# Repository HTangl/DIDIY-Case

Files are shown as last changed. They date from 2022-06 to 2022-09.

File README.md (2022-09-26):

# DIDIY Case

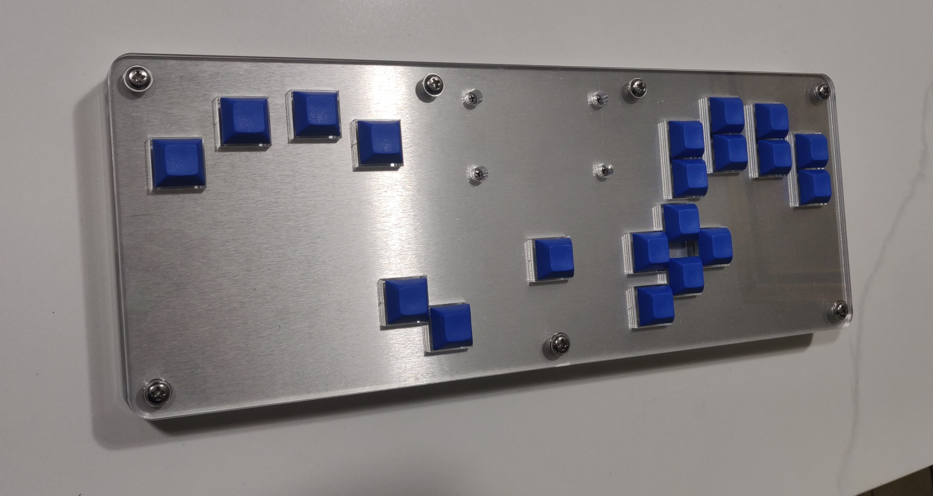
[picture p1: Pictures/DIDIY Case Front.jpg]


The DIDIY case is a case design specifically made for the [DIDIY board](https://github.com/HTangl/DIDIY). It uses the **[HTangl layout](https://www.htangl.com/layout)**

For a video guide on how to assemble the layered version of the case please visit the [HTangl YouTube channel](https://www.youtube.com/channel/UCIHJYzL-LAS2CVR-Q0J305w).  
Although this guide only shows the layered case the assembly is essentially the same for the 3D printable version, there are just less layers since the main part of the case is one big piece.
 
There are 2 versions of the case in this repository

## Layered Version

You can use the DXF files to order all the panels needed from a laser cutting website like [SendCutSend](https://sendcutsend.com/). There are other websites you can get the panels from, SCS is just the site I use. There is a guide on how to order the panels from SCS below.

If you would like to have 2 extra menu buttons for Select/Home make sure to use the DXF files in the "Select and Home buttons" folder. These replace the standard switch plate and top panel DXF files.

## 3D Printable Version

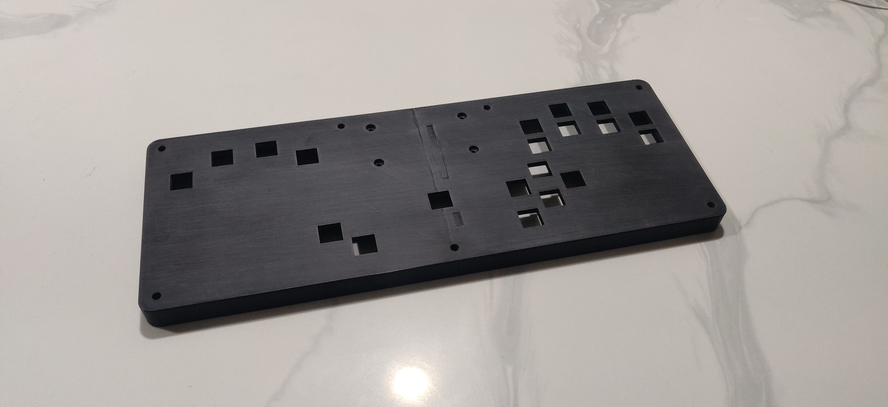
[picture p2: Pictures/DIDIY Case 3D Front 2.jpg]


You can use the STL files to print a case yourself, this version of the case still requires the hardware listed below minus the 8 M3 washers.

The main body of the case is printed in 2 halves which then slot together and are glued in place, while you can use super glue I recommend using a strong 2 part epoxy such as JB weld. The surface area is somewhat limited so the stronger the glue the better.

There are a few different ways to print a case, below are some suggestions.

**Fully Printed Option** - Print the main case + bottom and top panel, make sure to use the files in the "Select and Home buttons" folder if you want those buttons. You can exclude the top panel if you want to save filament/time, if you do this you will need to use 18mm case screws instead of the default 25mm ones.

**Print + Laser Cut Option** - Print the main case then use the DXF files to order 2 3mm top panels and 1 3mm bottom panel from SendCutSend, I recommend clear acrylic but you can use any material you want. This method has the advantage of allowing you to easily add artwork to the case. It also adds a little bit of rigidity because the top and bottom panels will be one big piece instead of split.

## Adding Artwork

If you want to add artwork to your case you can use the art template PDF's in this repository to design your own artwork and then either print it at home or at a print shop. I have a [guide on youtube](https://www.youtube.com/watch?v=gcbOZa_CNWk&t) that goes over how to prepare the file for printing, it was made for the HTangl but all the principals still apply.

## Hardware

For hardware you will need the following:  
7 - Case Screws - M5 x 0.80mm, 25mm Long  
7 - Case Nuts - M5 x 0.8 mm Weld Nuts  
4 - DIDIY Mounting Screws - M3 x 0.5mm, 8mm Long  
4 - DIDIY Mounting Nuts - M3 x 0.5 mm  
8 - Washers - M3 3.2 mm ID, 8 mm OD  

You can buy this hardware from me in a pack on my [Etsy shop](https://www.etsy.com/shop/HTangl) but if you'd prefer to source everything yourself below are links to the needed hardware on both McMaster-Carr and Amazon. McMaster will be higher quality but more expensive.  

McMaster-Carr  
https://www.mcmaster.com/92467A438/ - Case Screws  
https://www.mcmaster.com/90594A320/ - Case Nuts  
https://www.mcmaster.com/92000A118/ - DIDIY Mounting Screws  
https://www.mcmaster.com/91828A211/ - DIDIY Mounting Nuts  
https://www.mcmaster.com/95610A330/ - Washers  

Amazon  
https://amazon.com/dp/B08QHP1JK1 - Case Screws  
https://amazon.com/dp/B07H57TRN4 - Case Nuts  
https://amazon.com/dp/B01BBOZGKC - DIDIY Mounting Screws  
https://amazon.com/dp/B01IWUSDYY - DIDIY Mounting Nuts  
https://amazon.com/dp/B07MX9BMXM - Washers  

## SCS Ordering Guide

Here's a list of the material/thickness/quantity needed for each panel:  
Bottom Panel - Clear Acrylic 3mm - 1  
Middle Bottom Panel - Clear Acrylic 3mm - 2  
Middle Top Panel - Clear Acrylic 3mm - 3  
Switch Plate - 5052 Aluminum 1.6mm - 1  
Top Panel - Clear Acrylic 3mm - 2  

**Step 1**  
Download this repository by clicking on the green "Code" button at the top right of the page and then click "Download ZIP". Unzip the folder once it finishes downloading.  

**Step 2**  
Go to [SendCutSend](https://sendcutsend.com/) and click on "Get and instant quote"  
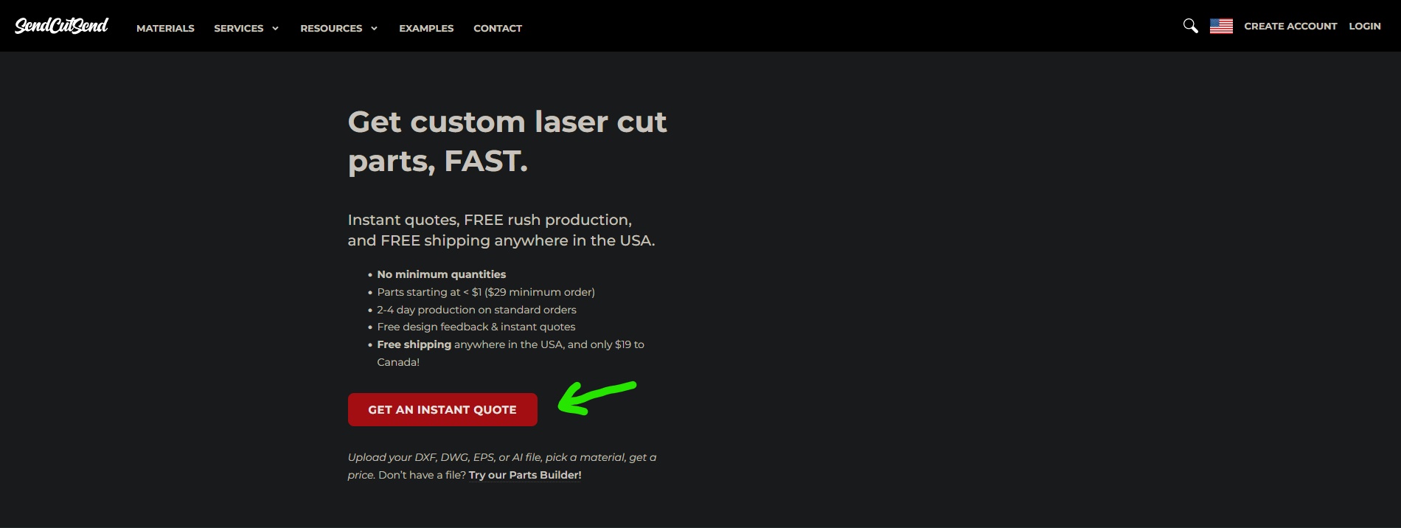
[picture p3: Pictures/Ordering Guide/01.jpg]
  

**Step 3**  
Open the DXF folder you downloaded in step 1 and drag one of the files onto the page to begin the ordering process, I started with the bottom panel.  
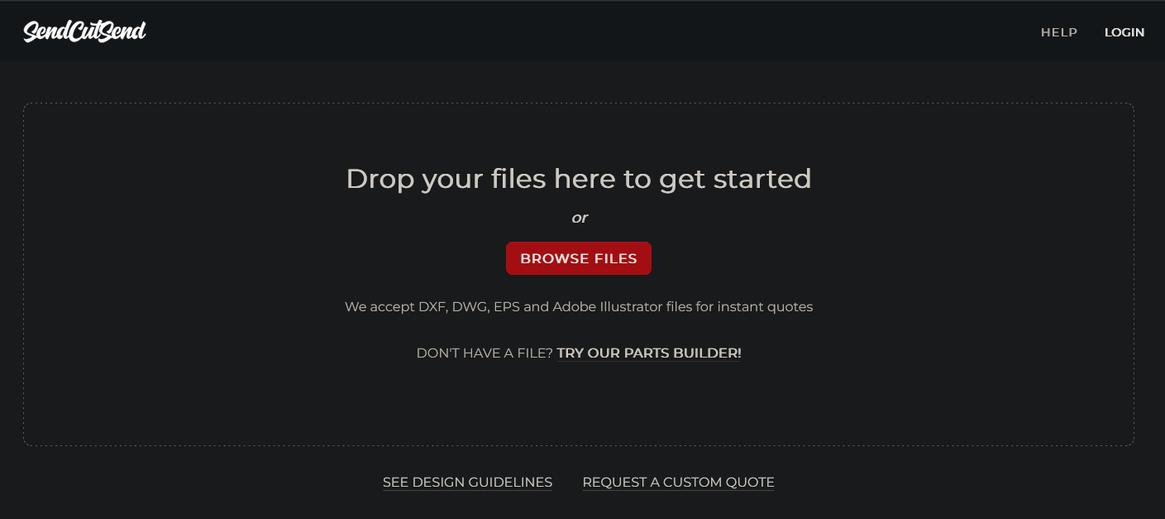
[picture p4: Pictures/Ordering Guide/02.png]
  

**Step 4**  
Click on the "Add to cart" button next to the file you just uploaded.  
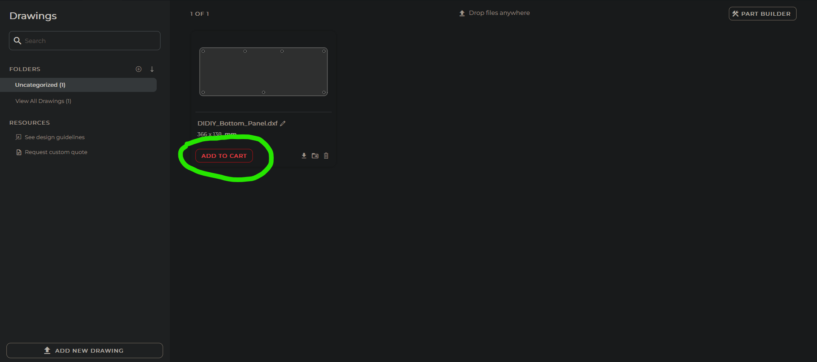
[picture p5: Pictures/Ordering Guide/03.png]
  

**Step 5**  
We now need to select what material to use for this panel, reference the list at the start of this guide to determine which material/thickness/quantity to select.  
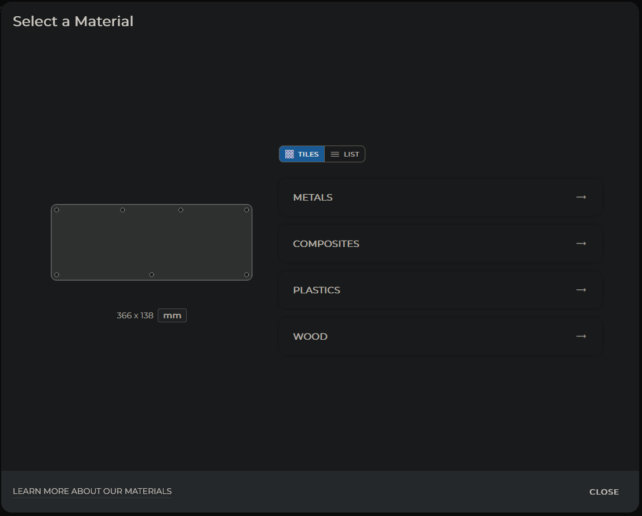
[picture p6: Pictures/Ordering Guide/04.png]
  

 **Step 6**  
 Once you reach this screen click "ADD TO CART", you will then get a notification that the item was added to your cart. You'll then need to click on "ADD MORE DRAWINGS", this will take you back to the screen you were at in step 4. All you need to do now is drag another DXF file onto the window and repeat the process for all the remaining panels.  
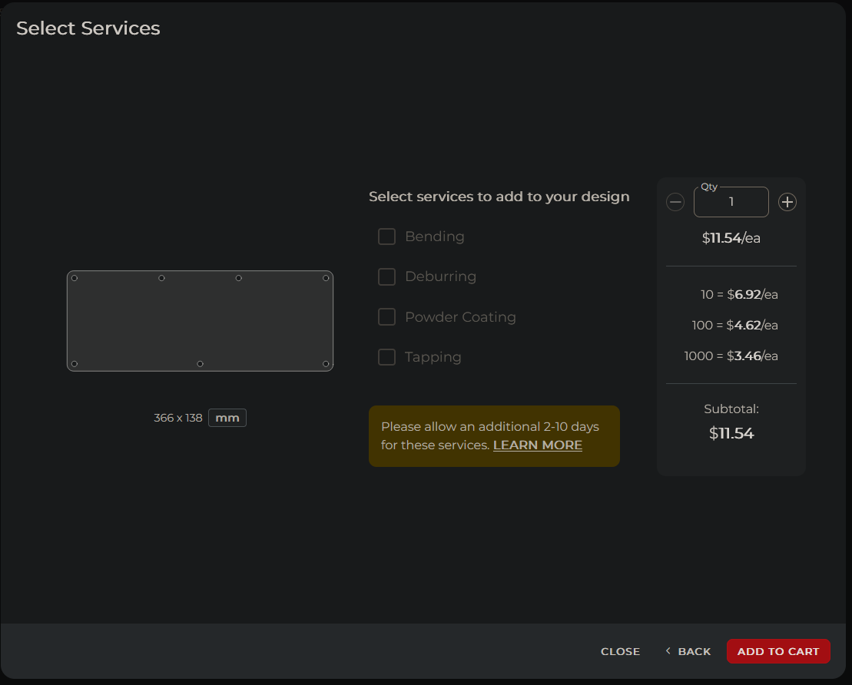
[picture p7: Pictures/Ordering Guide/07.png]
  

Please keep in mind that if you choose to deviate from the recommended material/thickness/quantity of any of these parts the case may not work with the recommended hardware or might not have enough space for the components/wiring to fit inside. Generally it's okay to change the type of material but I recommend sticking to the listed thickness/quantity for each panel.  

## License 

This repository is licensed under the CERN Open Hardware License Version 2 - Strongly Reciprocal. Please read the license in this repository and visit https://ohwr.org/cernohl for more information. This license allows you to make a modified or unmodified version of the case for yourself or to sell provided you follow the guidelines of the license. The strongly reciprocal version of the license I have chosen requires that you use this same license if you decide to make modifications to any of the files in this repository.

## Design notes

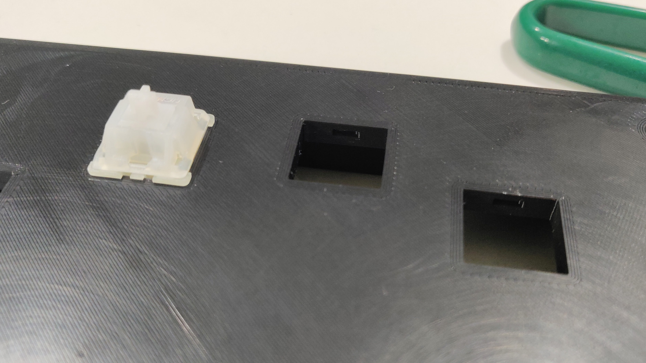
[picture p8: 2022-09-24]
Pictures/DIDIY Case 3D Clips.jpg

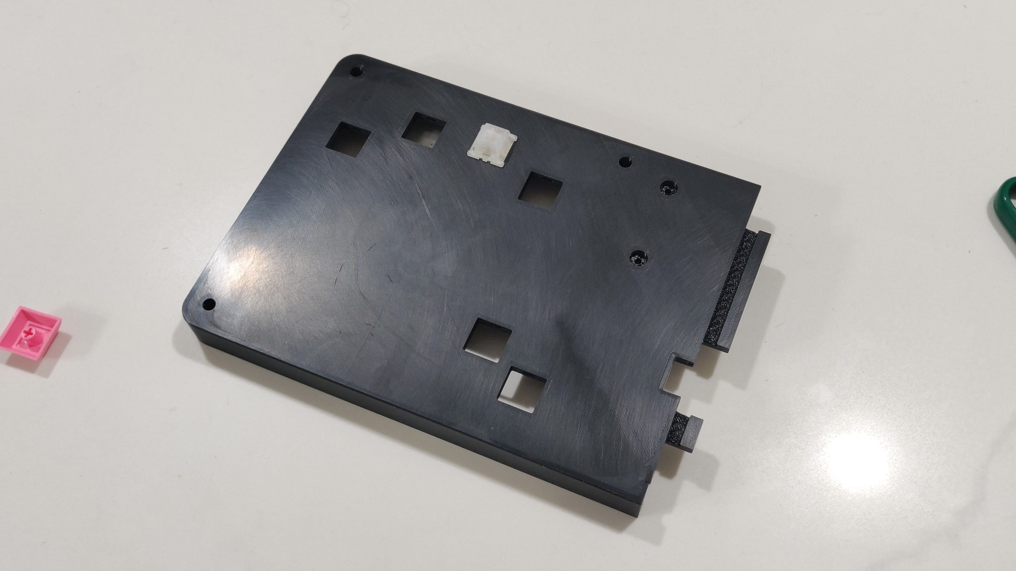
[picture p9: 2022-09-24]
Pictures/DIDIY Case 3D Left Half.jpg

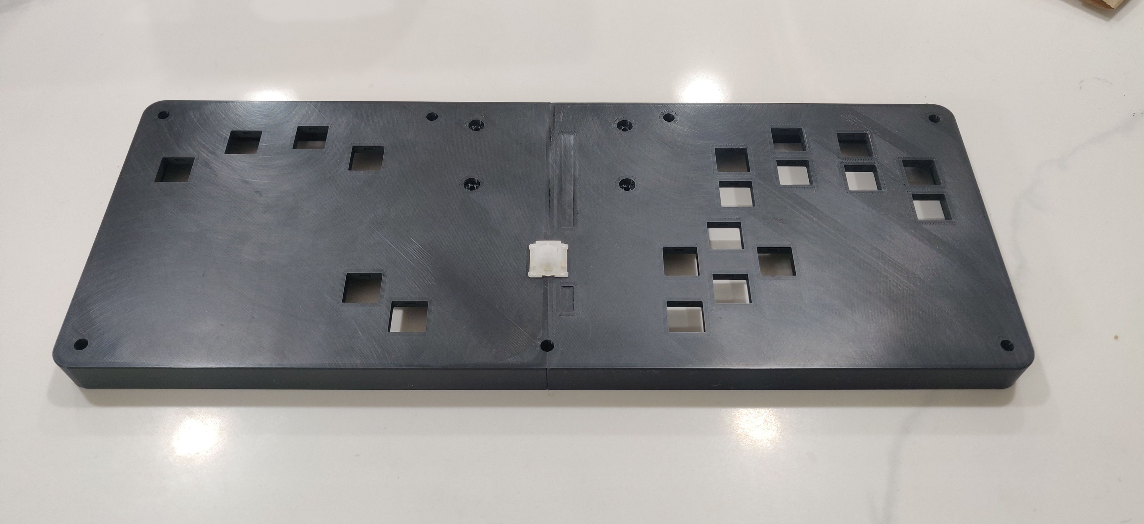
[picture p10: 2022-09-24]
Pictures/DIDIY Case 3D Front 1.jpg

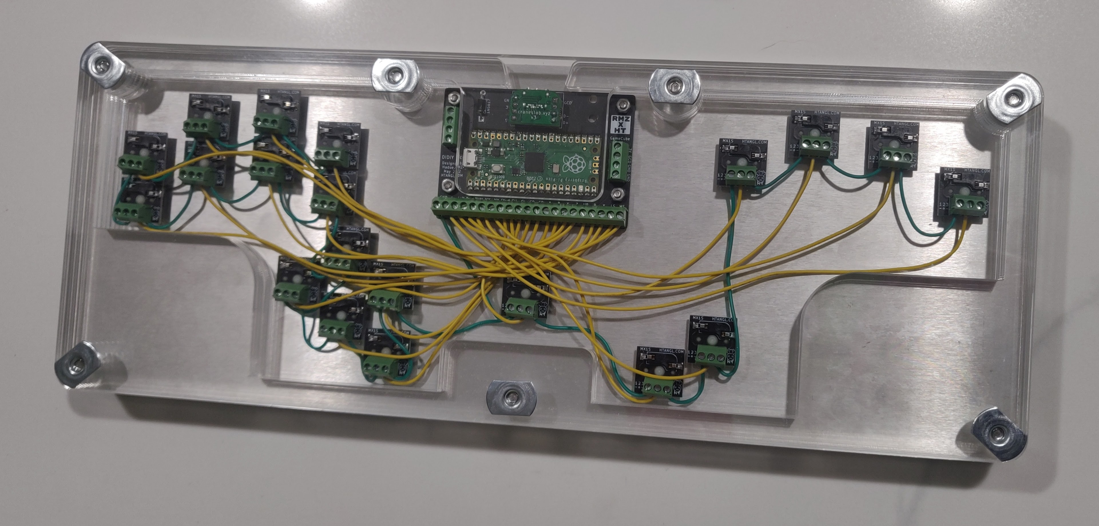
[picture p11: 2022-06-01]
Pictures/DIDIY Case Back.jpg

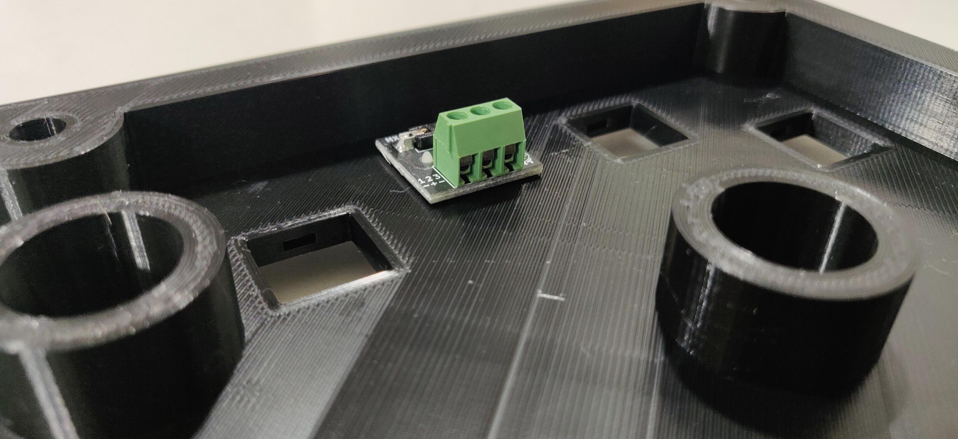
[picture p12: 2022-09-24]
Pictures/DIDIY Case 3D MX1S.jpg

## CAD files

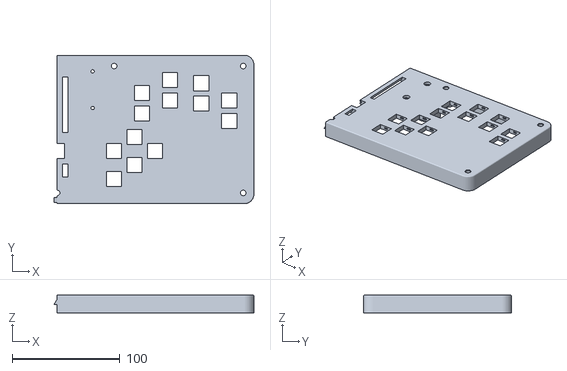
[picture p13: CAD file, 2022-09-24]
STL/Main Case Right.stl
185.9 x 138.0 x 16.6

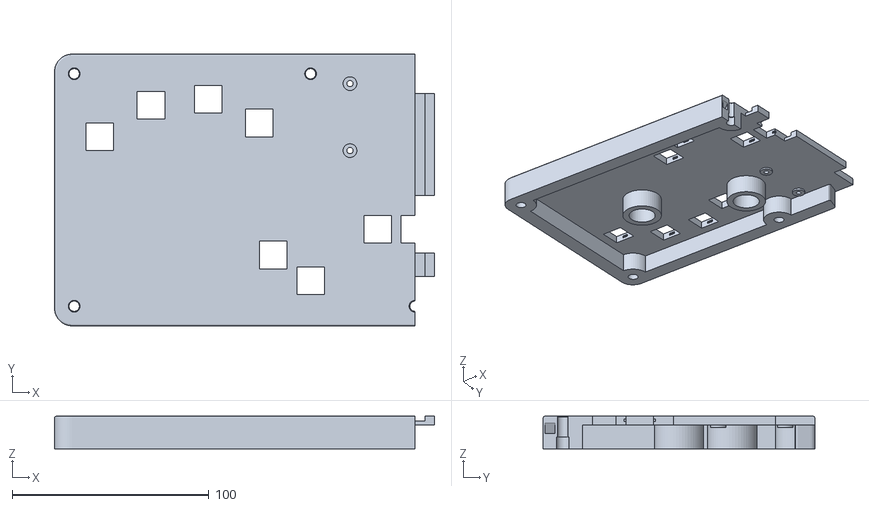
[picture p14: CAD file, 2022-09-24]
STL/Select and Home Buttons/Main Case SH Left.stl
192.9 x 138.0 x 16.6

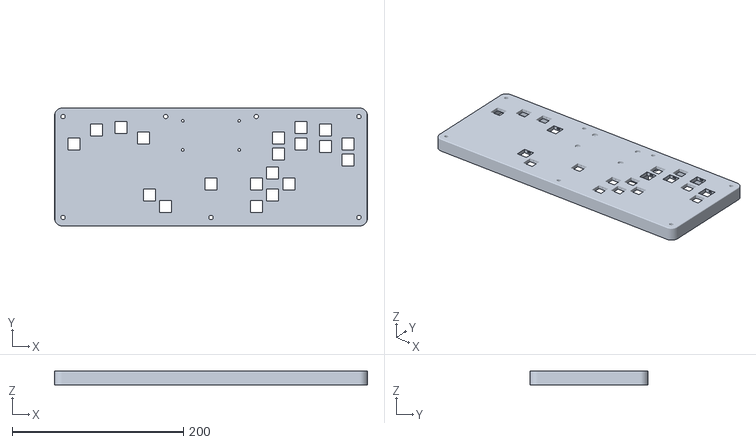
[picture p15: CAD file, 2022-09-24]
STL/Main Case Full.stl
366.0 x 138.0 x 16.6

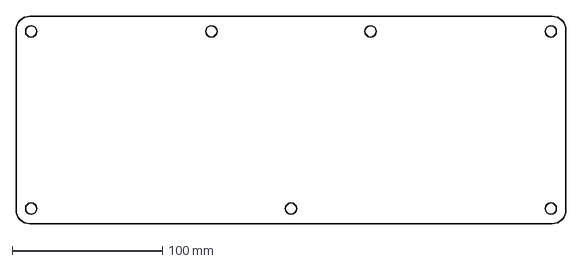
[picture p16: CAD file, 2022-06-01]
DXF/DIDIY Bottom Panel.dxf
366.0 x 138.0 mm

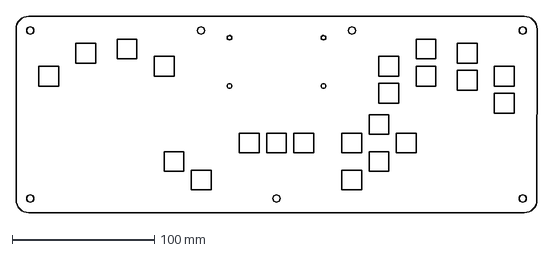
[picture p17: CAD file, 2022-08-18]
DXF/Select and Home buttons/DIDIY Switch Plate SH.dxf
366.0 x 138.0 mm

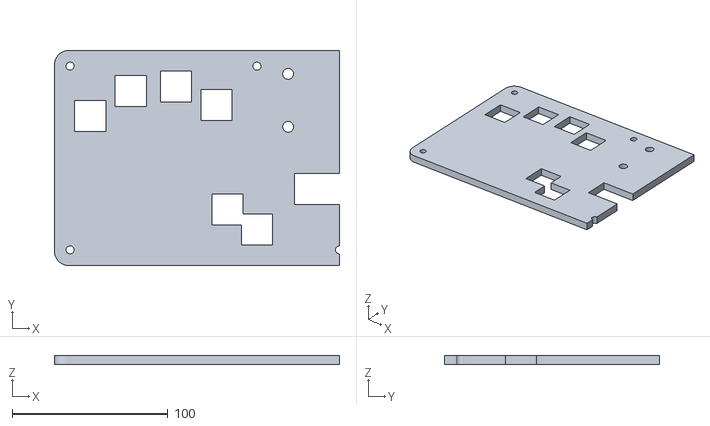
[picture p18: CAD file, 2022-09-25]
STL/Select and Home Buttons/Top Panel SH Left.stl
183.0 x 138.0 x 6.00

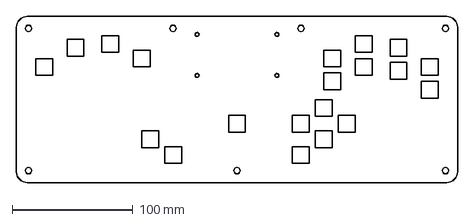
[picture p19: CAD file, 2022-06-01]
DXF/DIDIY Switch Plate.dxf
366.0 x 138.0 mm

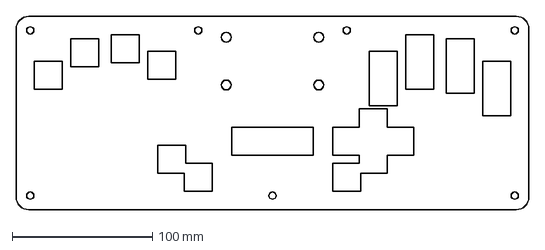
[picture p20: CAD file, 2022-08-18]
DXF/Select and Home buttons/DIDIY Top Panel SH.dxf
366.0 x 138.0 mm

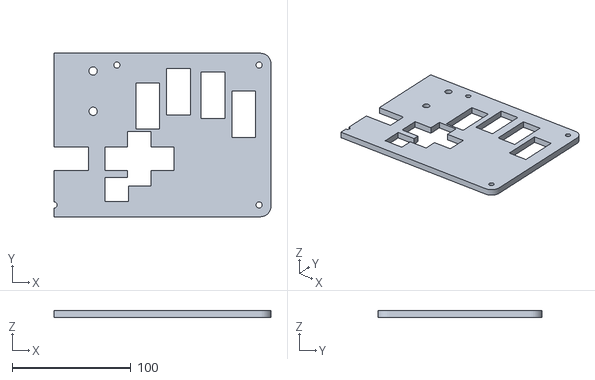
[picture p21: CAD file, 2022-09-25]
STL/Select and Home Buttons/Top Panel SH Right.stl
183.0 x 138.0 x 6.00

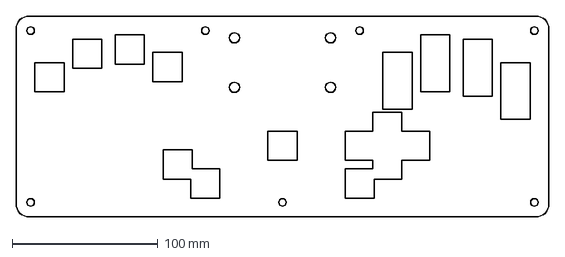
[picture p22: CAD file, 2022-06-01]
DXF/DIDIY Top Panel.dxf
366.0 x 138.0 mm

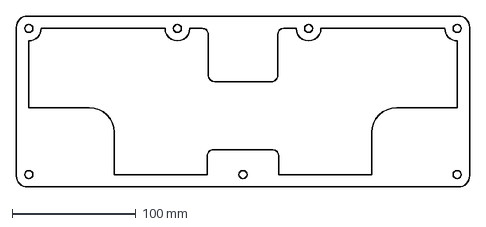
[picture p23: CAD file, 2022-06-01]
DXF/DIDIY Middle Bottom Panel.dxf
366.0 x 138.0 mm

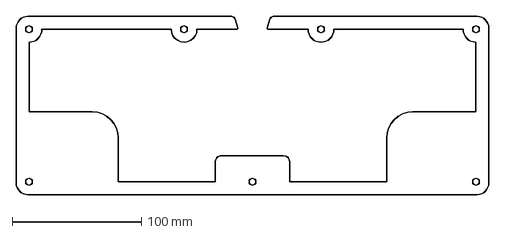
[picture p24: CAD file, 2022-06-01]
DXF/DIDIY Middle Top Panel.dxf
366.0 x 138.0 mm

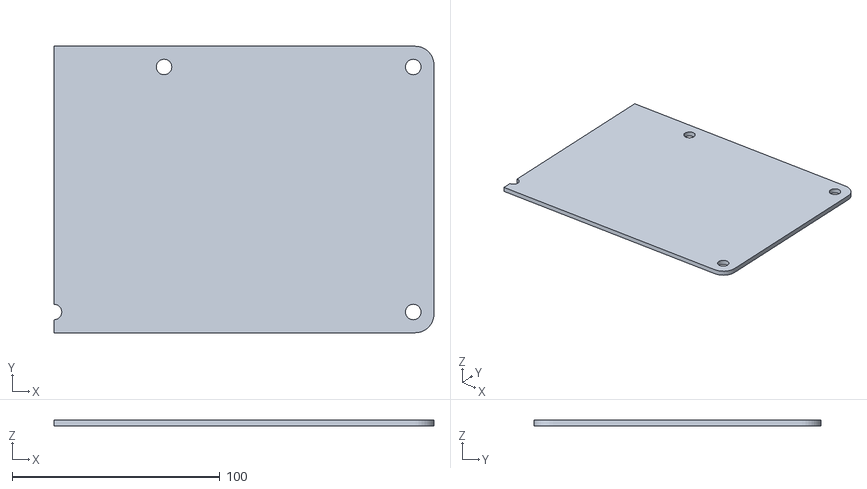
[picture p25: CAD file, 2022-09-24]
STL/Bottom Panel Right.stl
183.0 x 138.0 x 3.00

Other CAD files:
STL/Select and Home Buttons/Main Case SH Full.stl
STL/Main Case Left.stl
STL/Select and Home Buttons/Main Case SH Right.stl
STL/Top Panel Left.stl
STL/Top Panel Right.stl
F3D/Bottom Panel Full.f3d
F3D/Main Case Full.f3d
F3D/Main Case Left.f3d
F3D/Main Case Right.f3d
F3D/Select and Home Buttons/Main Case SH Full.f3d
F3D/Select and Home Buttons/Main Case SH Left.f3d
F3D/Select and Home Buttons/Main Case SH Right.f3d
F3D/Select and Home Buttons/Top Panel SH Full.f3d
F3D/Top Panel Full.f3d
STL/Bottom Panel Left.stl

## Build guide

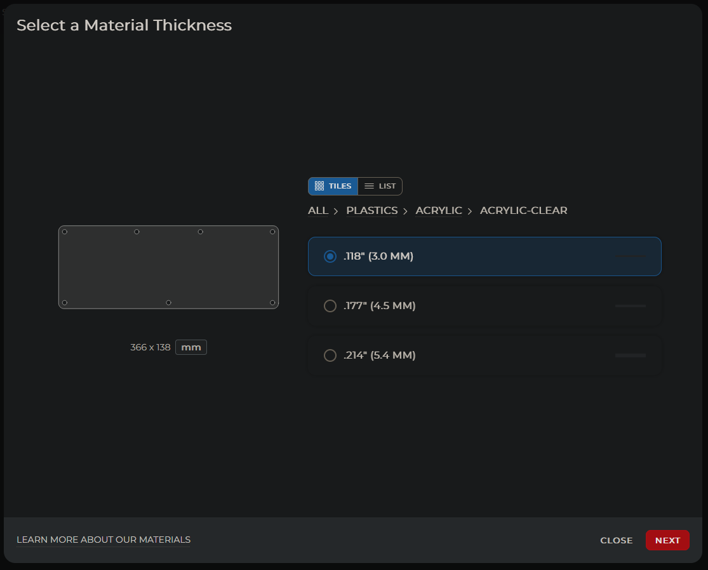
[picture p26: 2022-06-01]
Pictures/Ordering Guide/05.png

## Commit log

2022-08-18 Add DXF files with Select/Home buttons
    [DIDIY Switch Plate SH.dxf, DIDIY Top Panel SH.dxf]
2022-08-31 Add art template with select/home buttons
2022-09-24 Add 3D printable case files
    [DIDIY Bottom Panel Left.stl, DIDIY Bottom Panel Right.stl, DIDIY Top Panel Left.stl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]
2022-09-25 Changed top panel files to 6mm
    [Bottom Panel Left.stl, Bottom Panel Right.stl, DIDIY Top Panel Left.stl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]
2022-09-26 Add F3D files
    [Bottom Panel Full.f3d, Main Case Full.f3d, Main Case Left.f3d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]
